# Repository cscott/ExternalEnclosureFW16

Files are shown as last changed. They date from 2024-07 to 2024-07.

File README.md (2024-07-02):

# Input Module Adapter
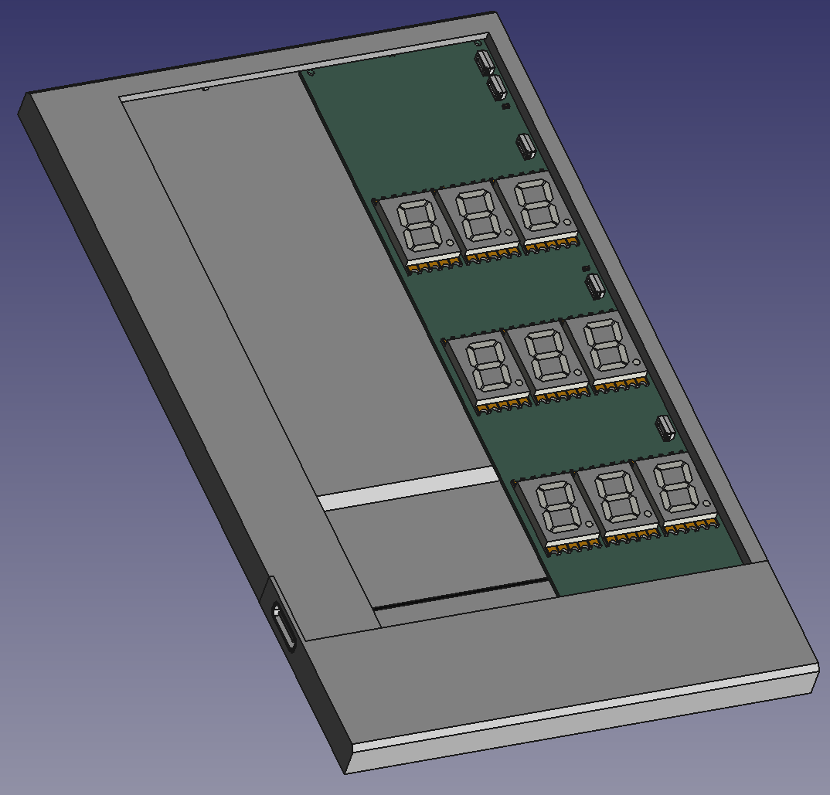
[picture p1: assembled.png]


This is a USB-C adapter to mount and use two small Input Modules or
one medium Input Module (like a numeric keypad) outside
of a Framework Laptop 16.  Note that the actual pogo pin connector is a 
custom Framework part which they have not made generally available;
I am using a pair of alternate connectors from Molex which are compatible.

The PCB incorporates a 4-port USB 2.0 hub, so that both input module
slots can be active.  If you only need the leftmost input module connector
to be functional (because you only want to use a medium-size Input Module,
for example), then you can omit many of the components and populate R3/R4/R5
as indicated on the [schematic](./SpringAdapter.pdf).

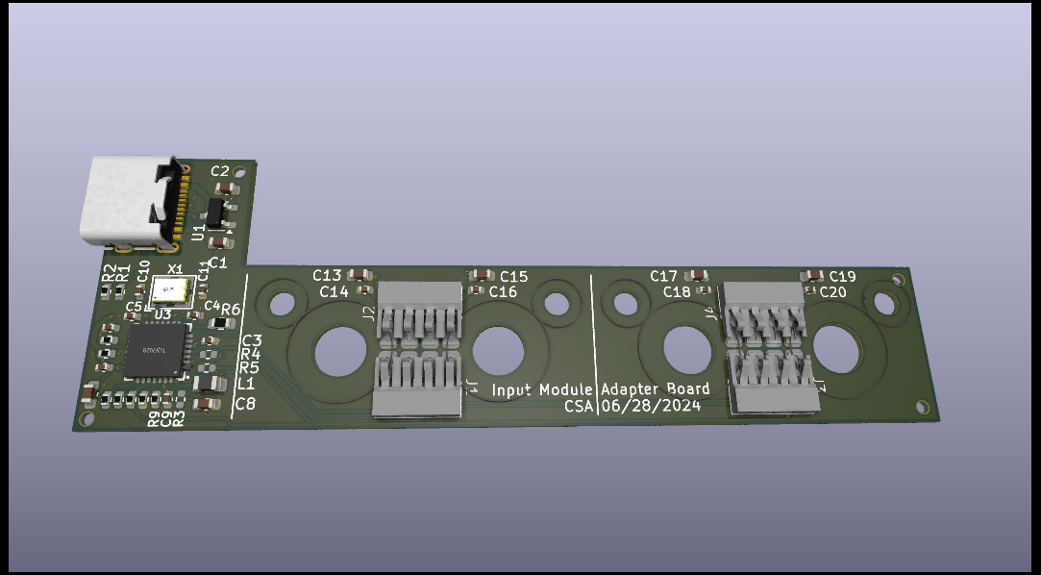
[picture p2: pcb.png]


Further discussion can be found on the Framework Community forums at
https://community.frame.work/t/external-usb-c-enclosure-for-input-modules/53695

## License
Input Modules © 2023 by Framework Computer Inc is licensed under CC BY 4.0.

This external enclosure is © 2024 by
C. Scott Ananian and is also licensed under CC BY 4.0.

To view a copy of this license,
visit http://creativecommons.org/licenses/by/4.0/

## Assembly and Fabrication

**THIS DESIGN HAS NOT YET BEEN TESTED. CAVEAT LECTOR.**

This has been designed for PCBA by JLCPCB, and appropriate LCSC parts
numbers are included in the kicad files.  Hand soldering the molex
input module connectors may be required, as JLC does not tend to keep
these in stock -- although you can special order them, you might
find it easier to [obtain them from DigiKey](https://www.digikey.com/en/products/detail/molex/0472861001/4553726)
and hand-solder them (or use a hot plate).

Use a 0.8mm PCB.  The needed files for JLCPCB fabrication are in
the [production](./production) directory.  Use `bom.csv` and `positions.csv`
for PCBA.

The enclosure and lid have been designed in FreeCad.  Some of the tolerances
and thicknesses might be challenging to print on a home 3d printer; I had
JLCPCB print these using SLS in black nylon; the STEP files are provided
in [External Enclosure.step](./External%20Enclosure.step) and
[Lid.step](./Lid.step).

To make Input Modules attach to the
adapter, you can glue in 5mm x 2mm cylindrical magnets or glue on
5mm x 5mm x 1.2mm square magnets.

There are recesses on the bottom surface for <=8mm rubber bumper feet,
like [these from DigiKey](https://www.digikey.com/en/products/detail/3m/SJ5076/570288) (but you can get these anywhere).

Use M2x6mm flathead fasteners as the alignment pins, with a M2 nut on the top
of the PCB (which also serves to secure the PCB in the case).  You can
probably get away with using pan head fasteners if the rubber bumpers are
tall enough.

There are cutouts for 3mm x 1.5mm cylindrical magnets on the front face
and on the lid to secure the lid.  Ensure the polarities are appropriate
such that the lid is attracted to the body of the enclosure!

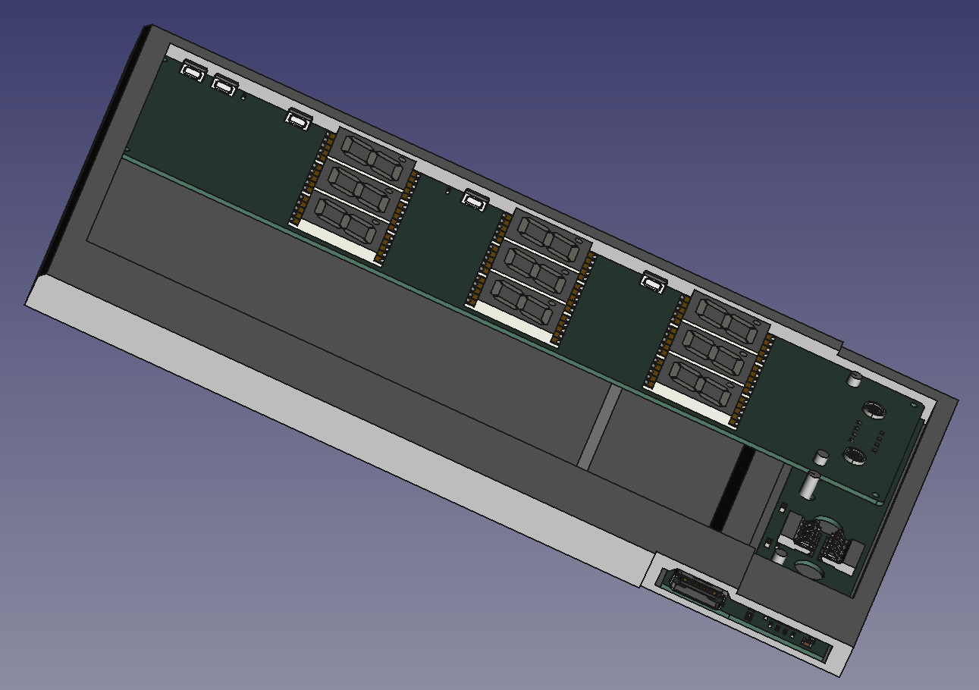
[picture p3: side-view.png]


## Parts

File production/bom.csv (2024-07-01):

Designator | Footprint | Quantity | Value | LCSC Part #
C1, C13, C15, C17, C19, C2, C6, C8 | 0603 | 8 | 10uF | C96446
C10, C11 | 0402 | 2 | 22pF | C1555
C12, C14, C16, C18, C20, C3, C4, C5, C7, C9 | 0402 | 10 | 100nF | C1525
J1, J2, J3, J4 | Molex_0472861001 | 4 | Molex 0472861001 | C6961828
L1 | 0805 | 1 | 10u | C1046
R1, R2 | 0402 | 2 | 5.1k | C25905
R10 | 0402 | 1 | 20k | C25765
R11 | 0402 | 1 | 100k | C25741
R12 | 0402 | 1 | 0 | C17168
R13, R8, R9 | 0402 | 3 | 10k | C25744
R6 | 0603 | 1 | 680 1% | C23228
R7 | 0402 | 1 | 47k | C25792
U1 | SOT-23-3 | 1 | XC6206P332MR-G | C5446
U3 | QFN-28_L5.0-W5.0-P0.50-BL-EP | 1 | GL852G-OHY60_C7501404 | C7501404
USB1 | USB-C-SMD_TYPE-C16PIN | 1 | TYPE-C 16PIN 3MD(385) | C2858270
X1 | OSC-SMD_4P-L3.2-W2.5-BL | 1 | 12MHz | C9002

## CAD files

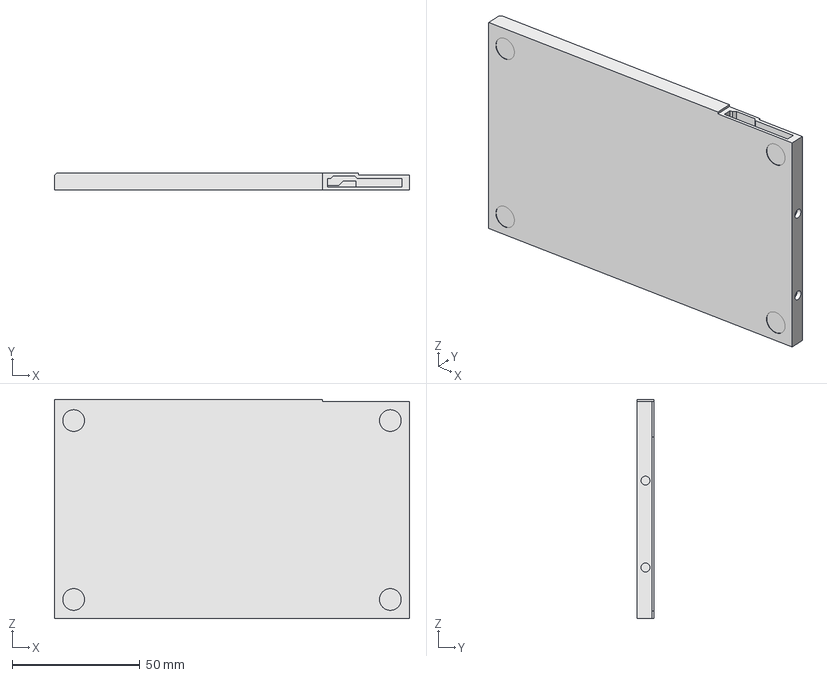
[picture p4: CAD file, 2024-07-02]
External Enclosure.step
138.9 x 6.70 x 85.8 mm

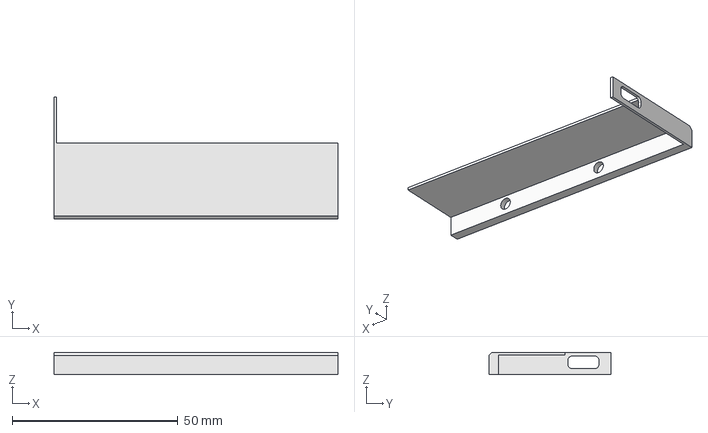
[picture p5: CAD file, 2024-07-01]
Lid.step
85.8 x 37.0 x 6.70 mm

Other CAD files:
external-enclosure.FCStd

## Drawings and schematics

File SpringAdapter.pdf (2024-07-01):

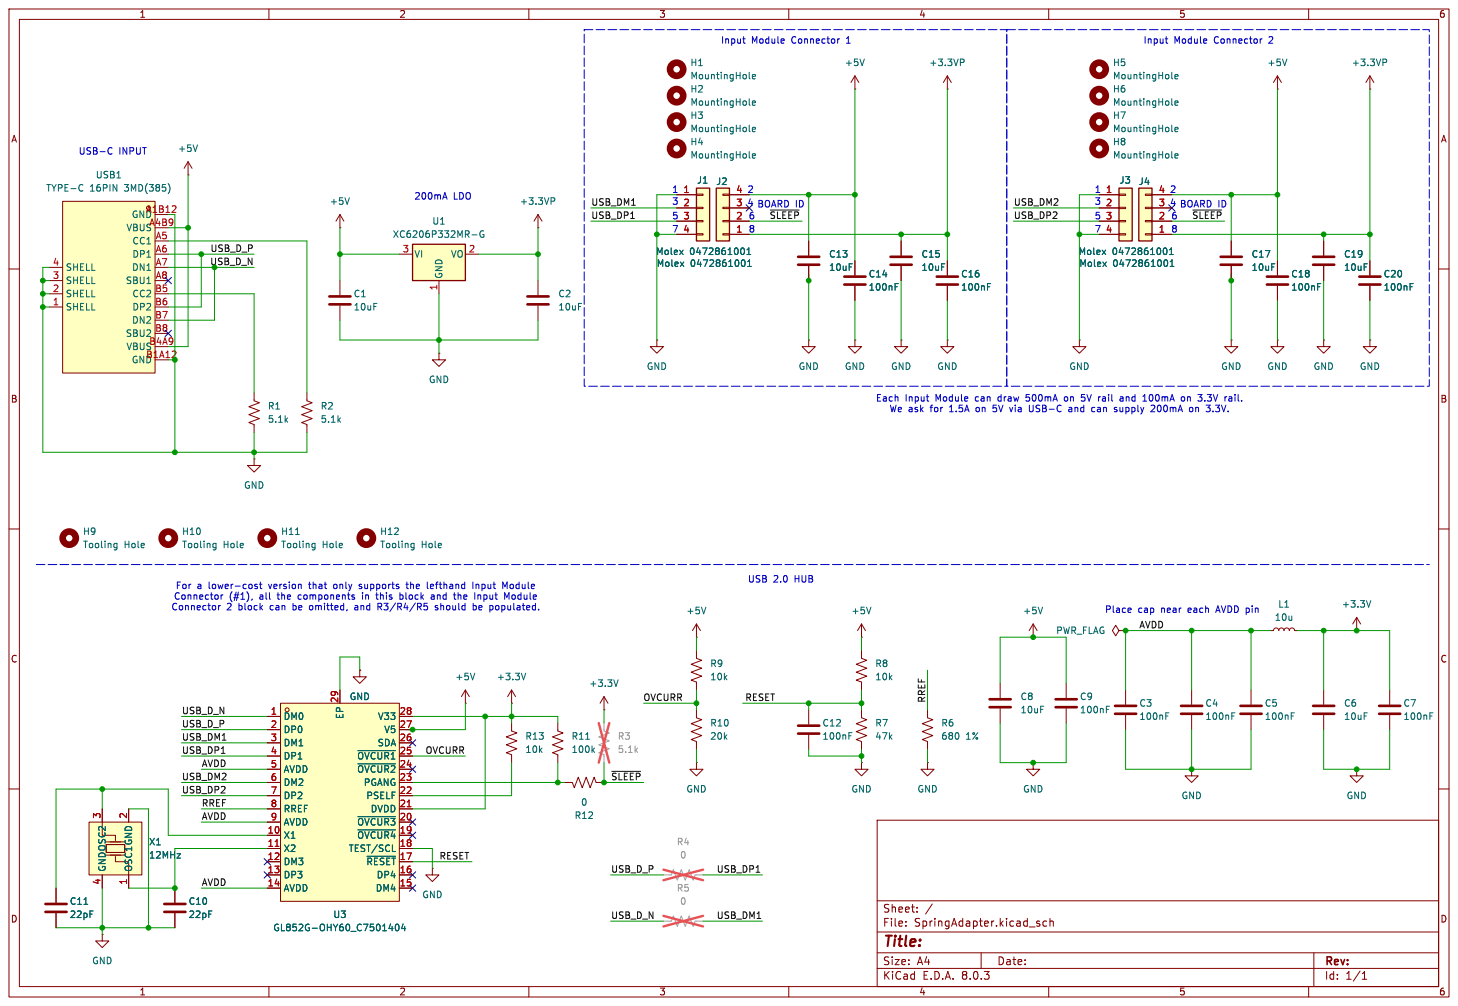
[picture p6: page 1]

Id: 1/1 Title: File: SpringAdapter.kicad_sch Sheet: / R3

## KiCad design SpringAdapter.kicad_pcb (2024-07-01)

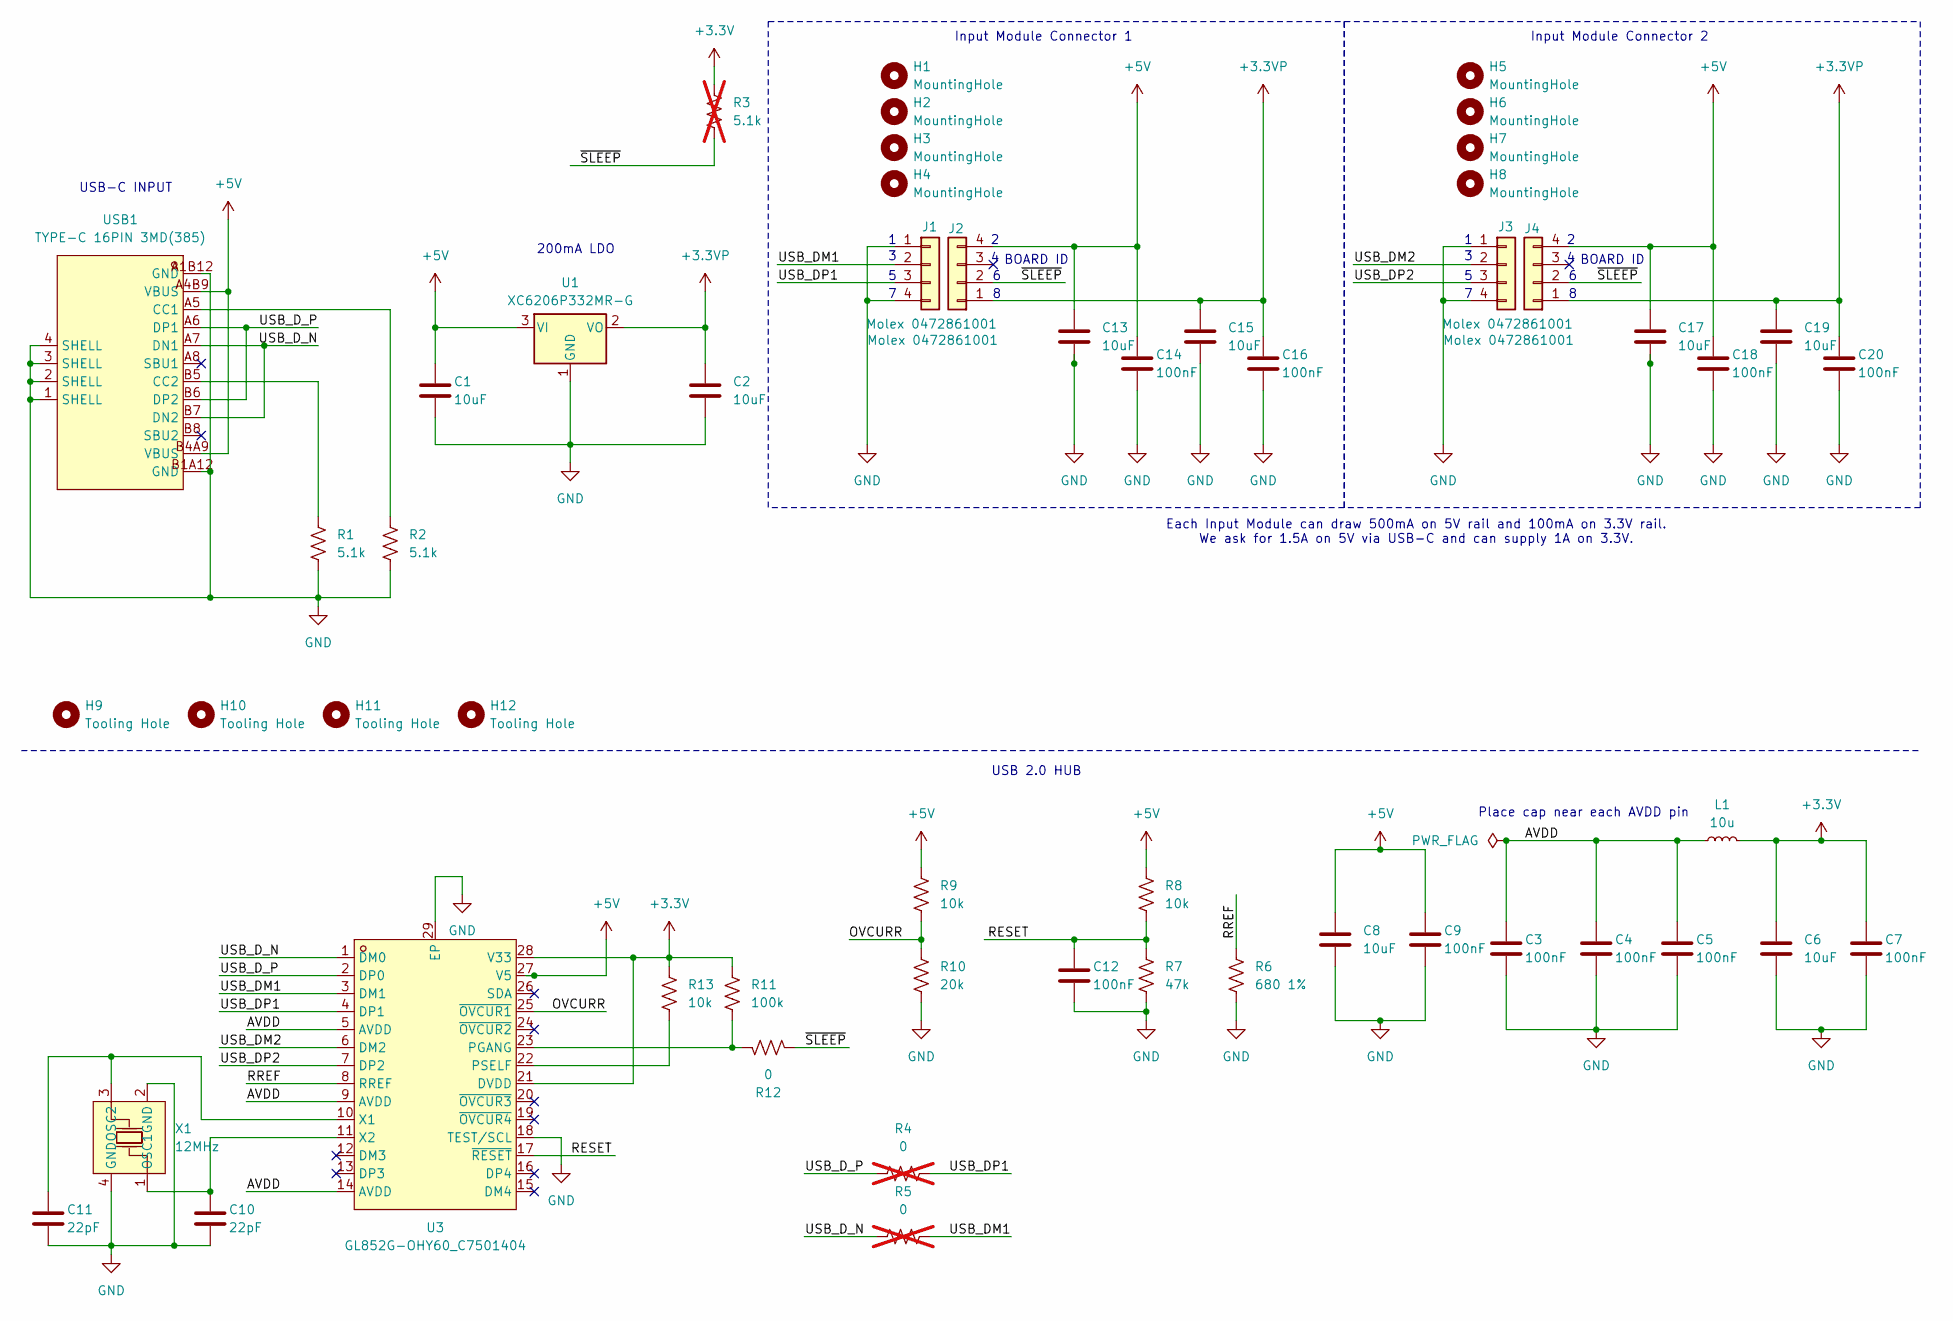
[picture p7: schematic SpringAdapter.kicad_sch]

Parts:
C1, C2, C6, C8, C13, C15, C17, C19: 10uF; C_0603_1608Metric; LCSC Part C96446
C3, C4, C5, C7, C9, C12, C14, C16, C18, C20: 100nF; C_0402_1005Metric; LCSC Part C1525
C10, C11: 22pF; C_0402_1005Metric; LCSC Part C1555
H1, H2, H5, H6: MountingHole; MountingHole_5mm
H3, H4, H7, H8: MountingHole; MountingHole_2.5mm
H9, H10, H11, H12: Tooling Hole; JLCPCB Tooling Hole
J1, J2, J3, J4: Molex 0472861001; Molex_0472861001; LCSC Part C6961828
L1: 10u; L_0805_2012Metric; LCSC Part C1046
R1, R2: 5.1k; R_0402_1005Metric; LCSC Part C25905
R3: 5.1k; R_0402_1005Metric; LCSC Part C25905; not fitted
R4, R5: 0; R_0402_1005Metric; LCSC Part C17168; not fitted
R6: 680 1%; R_0603_1608Metric; LCSC Part C23228
R7: 47k; R_0402_1005Metric; LCSC Part C25792
R8, R9, R13: 10k; R_0402_1005Metric; LCSC Part C25744
R10: 20k; R_0402_1005Metric; LCSC Part C25765
R11: 100k; R_0402_1005Metric; LCSC Part C25741
R12: 0; R_0402_1005Metric; LCSC Part C17168
U1: XC6206P332MR-G; SOT-23-3; LCSC Part C5446
U3: GL852G-OHY60_C7501404; QFN-28_L5.0-W5.0-P0.50-BL-EP; LCSC Part C7501404
USB1: TYPE-C 16PIN 3MD(385); USB-C-SMD_TYPE-C16PIN; LCSC Part C2858270
X1: 12MHz; OSC-SMD_4P-L3.2-W2.5-BL; LCSC Part C9002

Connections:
+3.3V: C6.1, C7.1, L1.2, R3.1, R11.1, R13.1, U3.21 (DVDD), U3.28 (V33)
+3.3VP: C2.1, C15.1, C16.1, C19.1, C20.1, J2.1, J4.1, U1.2 (VO)
+5V: C1.1, C8.1, C9.1, C13.1, C14.1, C17.1, C18.1, J2.4, J4.4, R8.1, R9.1, U1.3 (VI), U3.27 (V5), USB1.A4B9 (VBUS), USB1.B4A9 (VBUS)
/AVDD: C3.1, C4.1, C5.1, L1.1, U3.5 (AVDD), U3.9 (AVDD), U3.14 (AVDD)
/OVCURR: R9.2, R10.1, U3.25 (~OVCUR1)
/RESET: C12.1, R7.1, R8.2, U3.17 (~RESET)
/RREF: R6.1, U3.8 (RREF)
/USB_DM1: J1.2, R5.2, U3.3 (DM1)
/USB_DM2: J3.2, U3.6 (DM2)
/USB_DP1: J1.3, R4.2, U3.4 (DP1)
/USB_DP2: J3.3, U3.7 (DP2)
/USB_D_N: R5.1, U3.1 (DM0), USB1.A7 (DN1), USB1.B7 (DN2)
/USB_D_P: R4.1, U3.2 (DP0), USB1.A6 (DP1), USB1.B6 (DP2)
/~SLEEP: J2.2, J4.2, R3.2, R12.2
GND: C1.2, C2.2, C3.2, C4.2, C5.2, C6.2, C7.2, C8.2, C9.2, C10.2, C11.2, C12.2, C13.2, C14.2, C15.2, C16.2, C17.2, C18.2, C19.2, C20.2, J1.1, J1.4, J3.1, J3.4, R1.2, R2.2, R6.2, R7.2, R10.2, U1.1 (GND), U3.18 (TEST/SCL), U3.29 (EP), USB1.1 (SHELL), USB1.2 (SHELL), USB1.3 (SHELL), USB1.4 (SHELL), USB1.A1B12 (GND), USB1.B1A12 (GND), X1.2 (GND), X1.4 (GND)
unnamed: R11.2, R12.1, U3.23 (PGANG)
unnamed: R13.2, U3.22 (PSELF)
unnamed: C11.1, U3.10 (X1), X1.3 (OSC2)
unnamed: C10.1, U3.11 (X2), X1.1 (OSC1)
unnamed: R2.1, USB1.A5 (CC1)
unnamed: R1.1, USB1.B5 (CC2)

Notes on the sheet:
Place cap near each AVDD pin
200mA LDO
USB-C INPUT
BOARD ID
Input Module Connector 2
Input Module Connector 1
USB 2.0 HUB
Each Input Module can draw 500mA on 5V rail and 100mA on 3.3V rail. We ask for 1.5A on 5V via USB-C and can supply 1A on 3.3V.

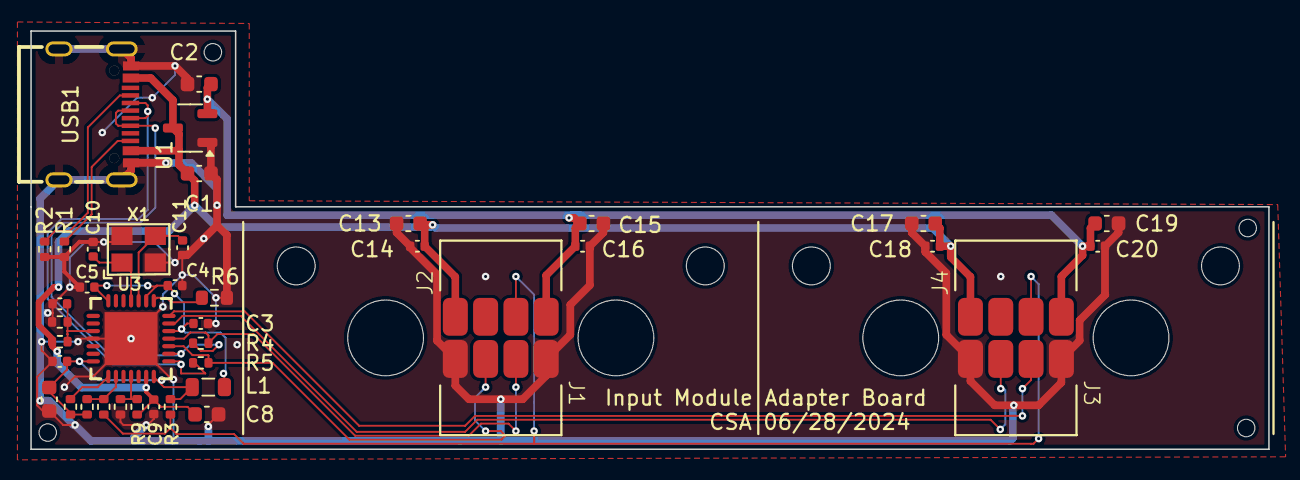
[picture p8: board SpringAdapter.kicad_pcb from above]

Board: 2 copper layers, 81.7 x 27.6 mm, 54 parts (0 on the bottom side), 21 nets.

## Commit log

2024-06-25 Initialize repository based on the "Spring Adapter" example from Framework
    [SpringAdapter.kicad_pcb, SpringAdapter.kicad_sch]
2024-06-29 Update repo to match JLCPCB parts, start adding USB hub
    [SpringAdapter.kicad_pcb, SpringAdapter.kicad_sch]
2024-06-30 First version complete
    [SpringAdapter.kicad_pcb, SpringAdapter.kicad_sch, bom.csv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]
2024-06-30 Enclosure design, part 1
    [SpringAdapter.kicad_pcb, external-enclosure.FCStd]
2024-07-01 more work on external enclosure
    [external-enclosure.FCStd]
2024-07-01 Move USB-C adapter up 1mm
    [SpringAdapter.kicad_pcb, external-enclosure.FCStd, positions.csv]
2024-07-01 First complete version of external enclosure
    [external-enclosure-External Enclosure001External Enclosure.step, external-enclosure-External Enclosure001Lid.step, external-enclosure.FCStd]
2024-07-01 DFM work
    [External Enclosure.step, Lid.step, SpringAdapter.kicad_pcb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]
2024-07-01 Documentation updates!
    [SpringAdapter.kicad_sch]
2024-07-02 Tweak 3d shapes for manufacturability
    Thinnest wall is now >= 0.8mm.
    [External Enclosure.step, external-enclosure.FCStd]
2024-07-02 Add link to forum thread
